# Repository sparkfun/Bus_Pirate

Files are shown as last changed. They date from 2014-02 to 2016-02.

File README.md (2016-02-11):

Bus Pirate
==========

Bus Pirate (https://cdn.sparkfun.com/assets/learn_tutorials/4/0/4/Bus_Pirate.jpg)

*Bus Pirate [(TOL-12942)](https://www.sparkfun.com/products/12942)*

This is a troubleshooting tool that communicates between a PC and any embedded device over most standard serial protocols, which
include I<sup>2</sup>C, SPI, and asynchronous serial.

Repository Contents
-------------------

* **/Hardware** &mdash; All Eagle design files (.brd, .sch)
* **/Production** &mdash; Production panel file (.brd)
* **/Software** &mdash; Minimal Python example demonstrating binary mode

Documentation
--------------
* **[Hookup Guide](https://learn.sparkfun.com/tutorials/bus-pirate-v36a-hookup-guide)** &mdash; Basic hookup guide for the Bus Pirate.
* **[SparkFun Fritzing repo](https://github.com/sparkfun/Fritzing_Parts)** &mdash; Fritzing diagrams for SparkFun products.

Product Versions
----------------
* [TOL-12942](https://www.sparkfun.com/products/12942) &mdash; Serial protocol troubleshooting tool

Version History
---------------
* [v3.6a](https://www.sparkfun.com/products/12942) &mdash; Updated main connector wire colors/locations and improved power regulation
* [v36](https://www.sparkfun.com/products/9544) &mdash; Original version produced by SparkFun

License Information
-------------------

This product is _**open source**_!

Please review the LICENSE.md file for license information.

If you have any questions or concerns on licensing, please contact techsupport@sparkfun.com.

Distributed as-is; no warranty is given.

- Your friends at SparkFun.

This is a collaboration with Ian Lesnet.

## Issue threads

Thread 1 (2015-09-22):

v3.6 Proto Checklist Issues

ericorosel, 2015-09-22:
(1) I think the Standoff drill hits should be part of a device and have a symbol in the SCH. We should use a standoff device with a symbol and a package from the eagle libraries. If we use a standardized device from the eagle library we can insure that the proper keepout and restrict elements are present, tested, and consistent.

(2) In the SCH the symbol for the cable connector uses a GND flag instead of a GND symbol on the GND net.

(3) USB connector currently has the wrong prefix in the Name field

(4) Level shifting IC currently has the wrong prefix in the Name field

(5) USB needs Tnames and Tvalues elements in the SCH

(6) 3.3V and 5V output traces from the vregs both have 20mil vias that are not masked on top or bottom. For testing purposes I only need the bottoms of the vias unmasked. Unless there is reasoning, I think the tops of these vias should be masked.

(7) VCC trace has two 20mil vias  that are not masked on top and bottom. I only need one of these vias unmasked on the bottom for testing (either one works for me), and unless there is reasoning, I think the tops of these vias should be masked.

(8) There are two GND vias that are unmasked on the top and the bottom. One is above the 1x5 header and one is to the left of the 2X5 connector. I think that both of these need mask on top and bottom unless there is a reason.

(9) R1, R5, R8 and all of the resistor arrays need some sort of silk in the package.

(10) Logic shifting IC needs a tPlace polarity marker that is outside of the package.

BrentWilkins, 2015-09-23:
(1) This isn't our design.  It's using the 'DP6037' standard PCB footprint.
(2) Changed to our standard.
(3) Using an industry standard name (https://en.wikipedia.org/wiki/Reference_designator) to not confuse it with a jumper (JP).  Not alright?
(4) Changed for similar reason as (3).
(5) FIxed on our library
(6) That is caused by our standard DRC by the limit option under masks.  Should I change the DRC? I unmasked one of the vias on the 5V bus for you on the bottom only.  Interesting that none of us have used larger vias for more current capacity and uncovered this before(?)
(7) See response to (6)
(8) See response to (6)
(9) Added a rectangle that doesn't overlap tStop
(10) Moved out

ericorosel, 2015-10-05:
Sorry it's been so long on this, I unsubscribe to repos so I never receive any notifications from activity on them.

(1) if the design is using a standard footprint 'DP6037' I think there needs to be a symbol for the footprint within schematic, or the standoffs need a symbol.

(2) Thanks

(3) We've (QC) been using the engineering 'eagle rules' wiki for reference on prefixes. I agree with you that JP is not the appropriate prefix per the industry standard, but according the the Engineering Wiki, it is what we use for connectors. Maybe there is en explanation from someone in engineering as to why we have a different set of prefixes than the industry standard.

(4) Thanks

(5) Thanks

(6) I see what you are talking about. I'm not entirely sure why we have the limit set to 20 mil. My only thought being that perhaps the drill is large enough that the mask would cover the metal on the top and the bottom of the via, but there would still be a hole that is not really masked closed? Or maybe it's something specific to GP? Having the vias unmasked on the top isn't the end of the world, but I would generally like to stay away from exposing metal unnecessarily, especially when it's metal on PWR or GND lines. Honestly, I think we could order protos with the tStop present, but I would like to get an explanation from engineering about why the 'limit' in the DRC is set to 20 mil.

(7) and (8) same as '(6)'

(9) thanks

(10) thanks

BrentWilkins, 2015-10-08:
(1) I copied the one from their library and increased the width of the dimension to meet our 8mil spec.
(3) The DFM group is aware of this.  We can change it later if we decide not to improve our rules. It shouldn't delay this project.
(6) I increased it to 30mil for this board and manually added bStop for VCC, 5V, SW3V3, & SW5V0.

ericorosel, 2015-10-08:
Pete informed me that the DFM group is looking into the prefixes that we use. Thanks for making that happen.

thanks for the fixes

Closed 2015-10-08.

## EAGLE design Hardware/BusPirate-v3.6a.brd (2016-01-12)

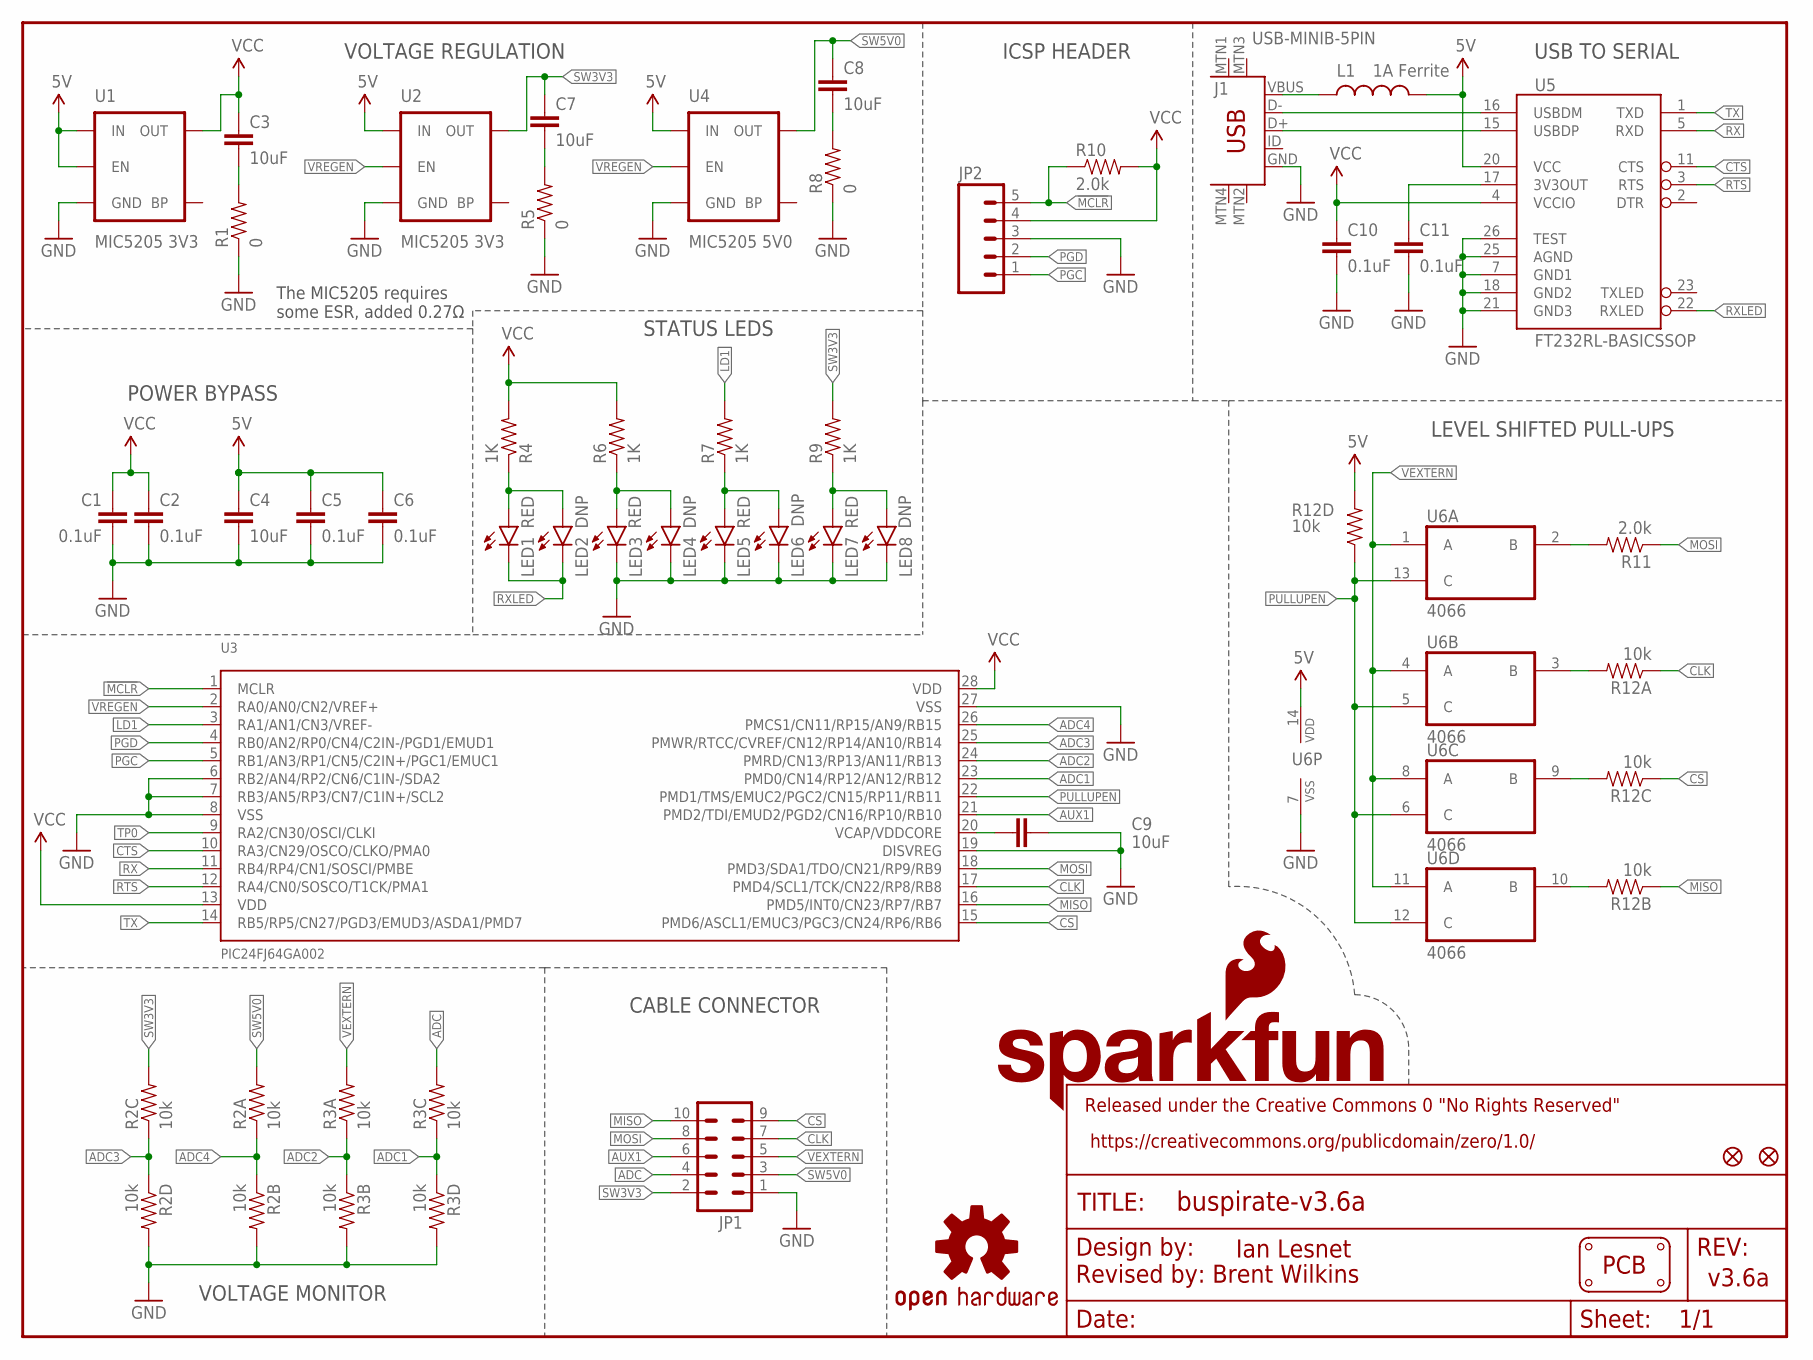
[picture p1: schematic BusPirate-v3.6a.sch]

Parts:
C1, C2, C5, C6, C10, C11: 0.1uF; 0603-CAP
C3, C4, C7, C8, C9: 10uF; 0805-CAP
FID1, FID2: FIDUCIAL1X2; FIDUCIAL-1X2
J1: USB-MINIB-5PIN; USB-MINIB
JP1: M05X2SHD_SMD; 2X5-SHROUDED_SMD
JP2: M05PTH; 1X05
L1: 1A Ferrite; 0603
LED1, LED3, LED5, LED7: RED; LED-0603
LED2, LED4, LED6, LED8: DNP; LED-0603
LOGO1: OSHW-LOGOL; OSHW-LOGO-L
LOGO2: SFE_LOGO_NAME_FLAME.1_INCH; SFE_LOGO_NAME_FLAME_.1
PCB1: PCB_DP_RECTANGLE-37X60; DP6037_V1
R1, R5, R8: 0; 0603
R2, R3, R12: 10k; 4XARRAY
R4, R6, R7, R9: 1K; 0603-RES
R10, R11: 2.0k; 0603-RES
U1, U2: MIC5205 3V3; SOT23-5
U3: PIC24FJ64GA002; SSOP28
U4: MIC5205 5V0; SOT23-5
U5: FT232RL-BASICSSOP; SSOP28DB
U6: 4066; TSSOP14

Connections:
5V: C4.1, C5.1, C6.1, L1.2, R12.5 (2), U1.1 (IN), U1.3 (EN), U2.1 (IN), U4.1 (IN), U5.20 (VCC), U6.14 (VDD)
!MCLR: JP2.5, R10.1, U3.1 (MCLR)
$N26: J1.VBUS, L1.1
ADC: JP1.4, R3.6 (2)
ADC1: R3.3 (1), R3.4 (1), U3.23 (PMD0/CN14/RP12/AN12/RB12)
ADC2: R3.1, R3.2 (1), U3.24 (PMRD/CN13/RP13/AN11/RB13)
ADC3: R2.3 (1), R2.4 (1), U3.25 (PMWR/RTCC/CVREF/CN12/RP14/AN10/RB14)
ADC4: R2.1, R2.2 (1), U3.26 (PMCS1/CN11/RP15/AN9/RB15)
AUX1: JP1.6, U3.21 (PMD2/TDI/EMUD2/PGD2/CN16/RP10/RB10)
CLK: JP1.7, R12.1, U3.17 (PMD4/SCL1/TCK/CN22/RP8/RB8)
CS: JP1.9, R12.3 (1), U3.15 (PMD6/ASCL1/EMUC3/PGC3/CN24/RP6/RB6)
CTS: U3.10 (RA3/CN29/OSCO/CLKO/PMA0), U5.11 (CTS)
D+: J1.D+, U5.15 (USBDP)
D-: J1.D-, U5.16 (USBDM)
GND: C1.2, C2.2, C4.2, C5.2, C6.2, C9.2, C10.2, C11.2, J1.GND, JP1.1, JP2.3, LED3.C, LED4.C, LED5.C, LED6.C, LED7.C, LED8.C, R1.1, R2.5 (2), R2.7 (2), R3.5 (2), R3.7 (2), R5.1, R8.1, U1.2 (GND), U2.2 (GND), U3.6 (RB2/AN4/RP2/CN6/C1IN-/SDA2), U3.7 (RB3/AN5/RP3/CN7/C1IN+/SCL2), U3.8 (VSS), U3.19 (DISVREG), U3.27 (VSS), U4.2 (GND), U5.7 (GND1), U5.18 (GND2), U5.21 (GND3), U5.25 (AGND), U5.26 (TEST), U6.7 (VSS)
LD1: R7.2, U3.3 (RA1/AN1/CN3/VREF-)
MISO: JP1.10, R12.2 (1), U3.16 (PMD5/INT0/CN23/RP7/RB7)
MOSI: JP1.8, R11.1, U3.18 (PMD3/SDA1/TDO/CN21/RP9/RB9)
unnamed: R11.2, U6.2 (B)
unnamed: R12.6 (2), U6.9 (B)
unnamed: C9.1, U3.20 (VCAP/VDDCORE)
unnamed: R12.7 (2), U6.10 (B)
unnamed: R12.8 (2), U6.3 (B)
unnamed: LED5.A, LED6.A, R7.1
unnamed: LED3.A, LED4.A, R6.1
unnamed: C3.2, R1.2
unnamed: C11.1, U5.17 (3V3OUT)
unnamed: C7.2, R5.2
unnamed: C8.2, R8.2
unnamed: LED1.A, LED2.A, R4.1
unnamed: LED7.A, LED8.A, R9.1
PGC: JP2.1, U3.5 (RB1/AN3/RP1/CN5/C2IN+/PGC1/EMUC1)
PGD: JP2.2, U3.4 (RB0/AN2/RP0/CN4/C2IN-/PGD1/EMUD1)
PULLUPEN: R12.4 (1), U3.22 (PMD1/TMS/EMUC2/PGC2/CN15/RP11/RB11), U6.5 (C), U6.6 (C), U6.12 (C), U6.13 (C)
RTS: U3.12 (RA4/CN0/SOSCO/T1CK/PMA1), U5.3 (RTS)
RX: U3.11 (RB4/RP4/CN1/SOSCI/PMBE), U5.5 (RXD)
RXLED: LED1.C, LED2.C, U5.22 (RXLED)
SW3V3: C7.1, JP1.2, R2.6 (2), R9.2, U2.5 (OUT)
SW5V0: C8.1, JP1.3, R2.8 (2), U4.5 (OUT)
TP0: U3.9 (RA2/CN30/OSCI/CLKI)
TX: U3.14 (RB5/RP5/CN27/PGD3/EMUD3/ASDA1/PMD7), U5.1 (TXD)
VCC: C1.1, C2.1, C3.1, C10.1, JP2.4, R4.2, R6.2, R10.2, U1.5 (OUT), U3.13 (VDD), U3.28 (VDD), U5.4 (VCCIO)
VEXTERN: JP1.5, R3.8 (2), U6.1 (A), U6.4 (A), U6.8 (A), U6.11 (A)
VREGEN: U2.3 (EN), U3.2 (RA0/AN0/CN2/VREF+), U4.3 (EN)

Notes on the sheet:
Revised by: Brent Wilkins
Ian Lesnet
v3.6a
VOLTAGE REGULATION
VOLTAGE MONITOR
USB TO SERIAL
STATUS LEDS
POWER BYPASS
ICSP HEADER
LEVEL SHIFTED PULL-UPS
CABLE CONNECTOR
The MIC5205 requires some ESR, added 0.27Ω
Date:
Sheet:
REV:
TITLE:
Released under the Creative Commons 0 "No Rights Reserved"
https://creativecommons.org/publicdomain/zero/1.0/
Design by:

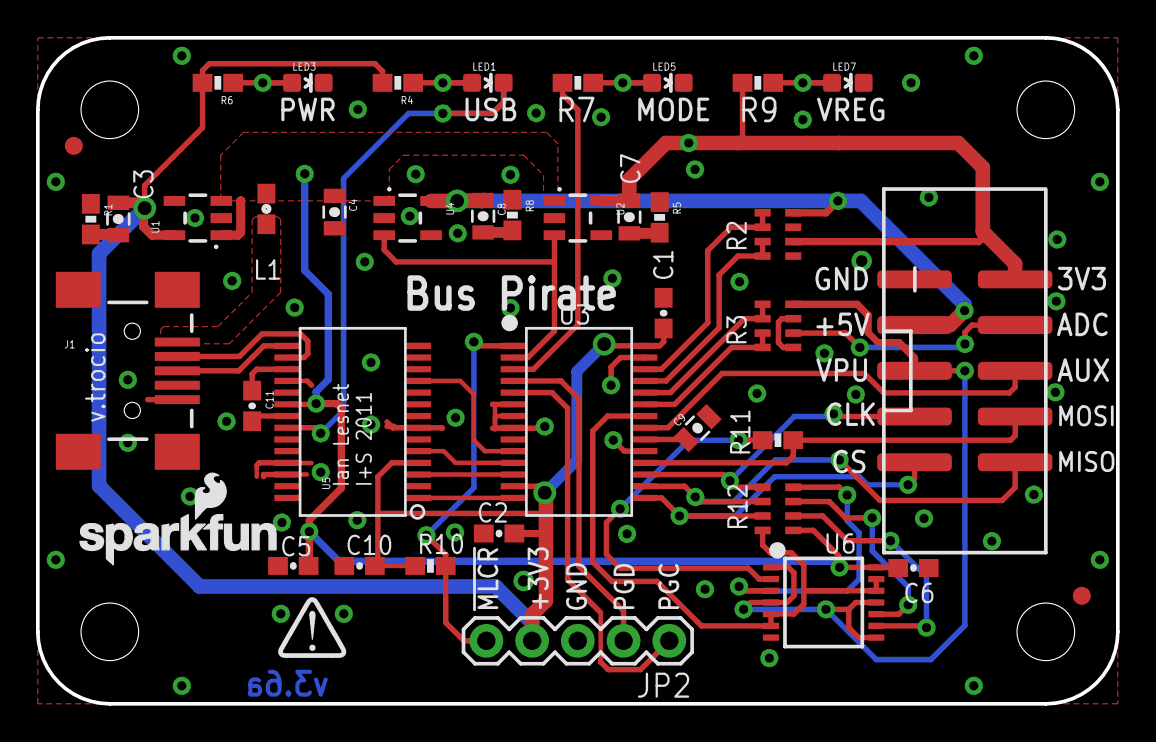
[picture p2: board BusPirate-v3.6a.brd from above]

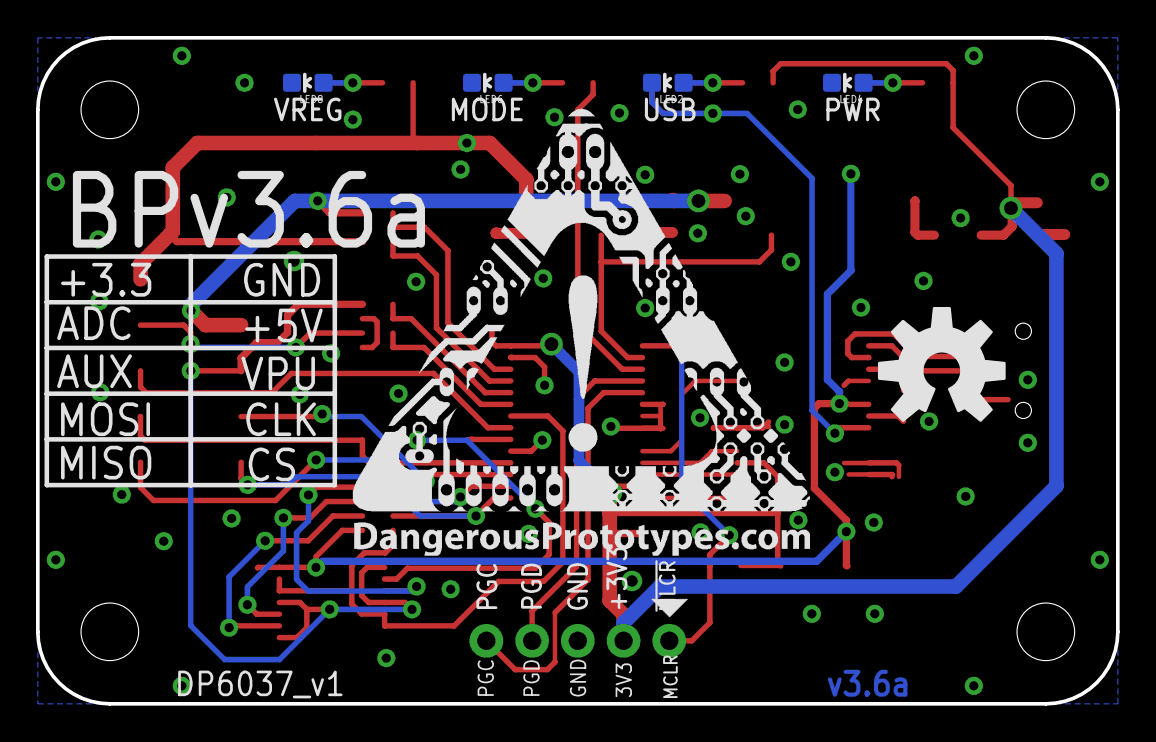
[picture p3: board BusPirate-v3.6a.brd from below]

Board: 2 copper layers, 60.0 x 37.0 mm, 48 parts (6 on the bottom side), 43 nets.

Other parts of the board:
U$1: DP-LOGO
U$3: DP_LOGO_ART_1X1

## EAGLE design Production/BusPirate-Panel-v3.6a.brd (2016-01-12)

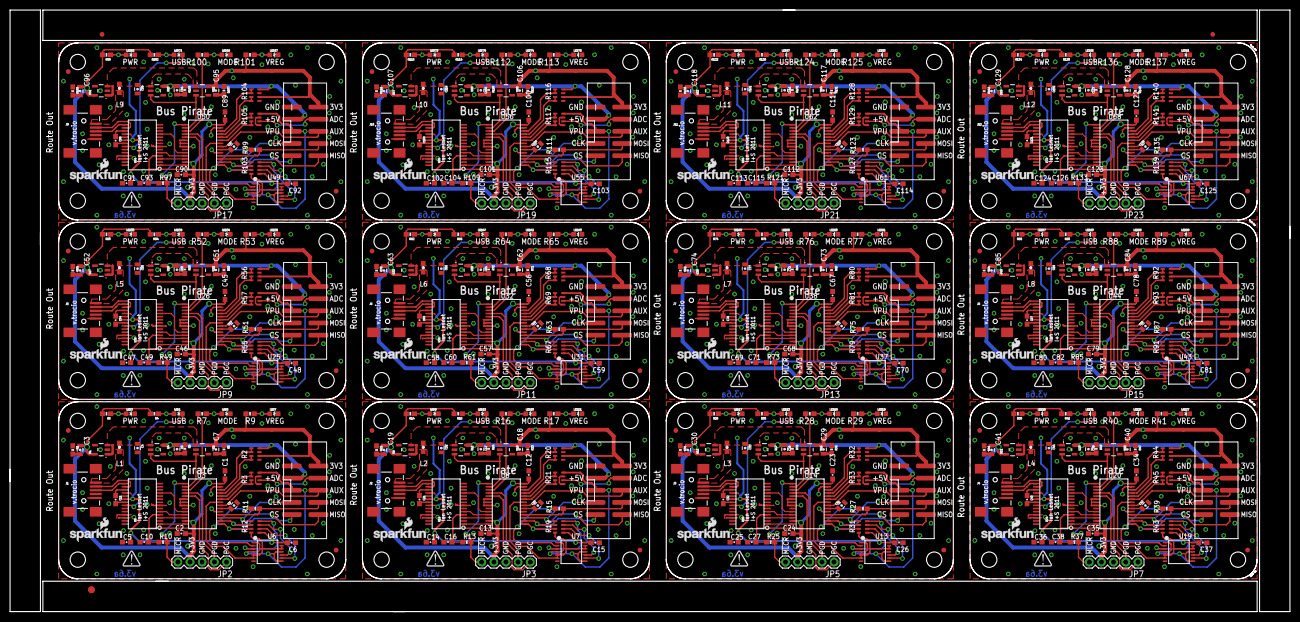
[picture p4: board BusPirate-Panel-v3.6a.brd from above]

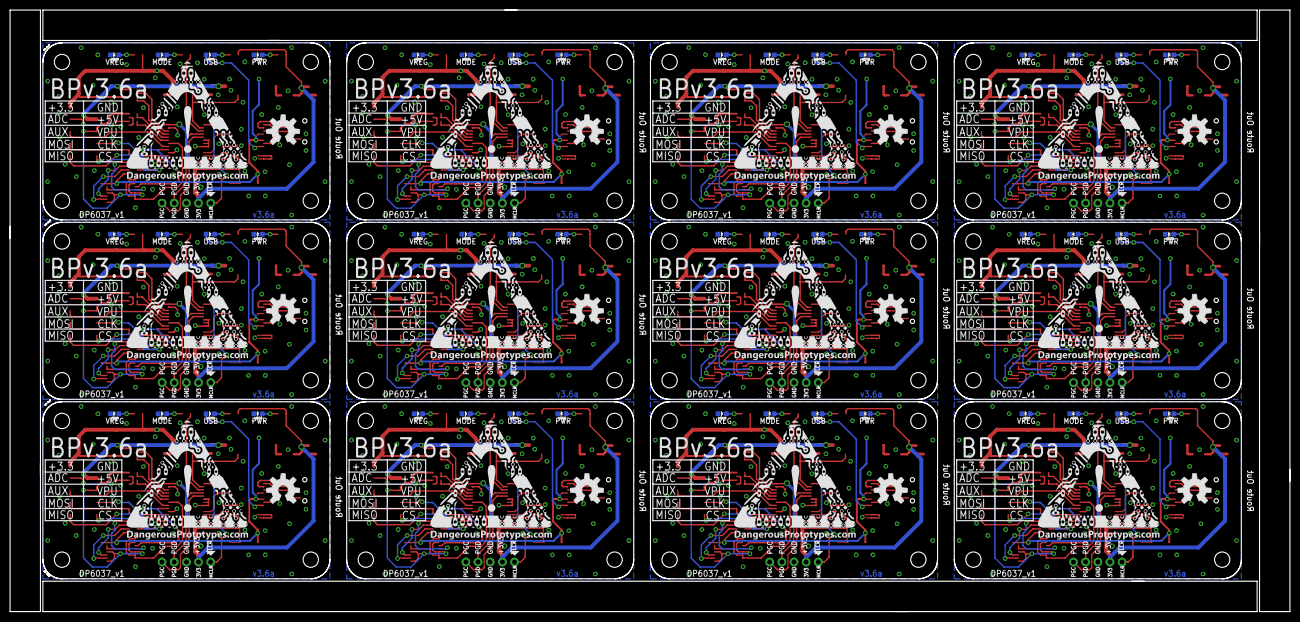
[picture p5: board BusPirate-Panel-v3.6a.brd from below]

Board: 2 copper layers, 267.5 x 125.7 mm, 579 parts (72 on the bottom side), 516 nets.

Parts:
C1, C2, C5, C6, C10, C11, C12, C13, C14, C15, C16, C21, C23, C24, C25, C26, C27, C32, C34, C35, C36, C37, C38, C43, C45, C46, C47, C48, C49, C54, C56, C57, C58, C59, C60, C65, C67, C68, C69, C70, C71, C76, C78, C79, C80, C81, C82, C87, C89, C90, C91, C92, C93, C98, C100, C101, C102, C103, C104, C109, C111, C112, C113, C114, C115, C120, C122, C123, C124, C125, C126, C131: 0.1uF; 0603-CAP
C3, C4, C7, C8, C9, C17, C18, C19, C20, C22, C28, C29, C30, C31, C33, C39, C40, C41, C42, C44, C50, C51, C52, C53, C55, C61, C62, C63, C64, C66, C72, C73, C74, C75, C77, C83, C84, C85, C86, C88, C94, C95, C96, C97, C99, C105, C106, C107, C108, C110, C116, C117, C118, C119, C121, C127, C128, C129, C130, C132: 10uF; 0805-CAP
E$1: FIDUCIAL-1.5X3
E$7, E$8: FIDUCIAL-1X2
FID1, FID2, FID3, FID4, FID5, FID6, FID7, FID8, FID9, FID10, FID11, FID12, FID13, FID14, FID15, FID16, FID17, FID18, FID19, FID20, FID21, FID22, FID23, FID24: FIDUCIAL1X2; FIDUCIAL-1X2
J1, J2, J3, J4, J5, J6, J7, J8, J9, J10, J11, J12: USB-MINIB-5PIN; USB-MINIB
JP1, JP4, JP6, JP8, JP10, JP12, JP14, JP16, JP18, JP20, JP22, JP24: 2X5-SHROUDED_SMD
JP2, JP3, JP5, JP7, JP9, JP11, JP13, JP15, JP17, JP19, JP21, JP23: 1X05
L1, L2, L3, L4, L5, L6, L7, L8, L9, L10, L11, L12: 1A Ferrite; 0603
LED1, LED3, LED5, LED7, LED9, LED10, LED11, LED15, LED17, LED18, LED19, LED23, LED25, LED26, LED27, LED31, LED33, LED34, LED35, LED39, LED41, LED42, LED43, LED47, LED49, LED50, LED51, LED55, LED57, LED58, LED59, LED63, LED65, LED66, LED67, LED71, LED73, LED74, LED75, LED79, LED81, LED82, LED83, LED87, LED89, LED90, LED91, LED95: RED; LED-0603
LED2, LED4, LED6, LED8, LED12, LED13, LED14, LED16, LED20, LED21, LED22, LED24, LED28, LED29, LED30, LED32, LED36, LED37, LED38, LED40, LED44, LED45, LED46, LED48, LED52, LED53, LED54, LED56, LED60, LED61, LED62, LED64, LED68, LED69, LED70, LED72, LED76, LED77, LED78, LED80, LED84, LED85, LED86, LED88, LED92, LED93, LED94, LED96: DNP; LED-0603
LOGO1, LOGO4, LOGO6, LOGO8, LOGO10, LOGO12, LOGO14, LOGO16, LOGO18, LOGO20, LOGO22, LOGO24: OSHW-LOGOL; OSHW-LOGO-L
LOGO2, LOGO3, LOGO5, LOGO7, LOGO9, LOGO11, LOGO13, LOGO15, LOGO17, LOGO19, LOGO21, LOGO23: SFE_LOGO_NAME_FLAME.1_INCH; SFE_LOGO_NAME_FLAME_.1
PCB1, PCB2, PCB3, PCB4, PCB5, PCB6, PCB7, PCB8, PCB9, PCB10, PCB11, PCB12: PCB_DP_RECTANGLE-37X60; DP6037_V1
R1, R5, R8, R22, R23, R24, R34, R35, R36, R46, R47, R48, R58, R59, R60, R70, R71, R72, R82, R83, R84, R94, R95, R96, R106, R107, R108, R118, R119, R120, R130, R131, R132, R142, R143, R144: 0; 0603
R2, R3, R12, R19, R20, R21, R31, R32, R33, R43, R44, R45, R55, R56, R57, R67, R68, R69, R79, R80, R81, R91, R92, R93, R103, R104, R105, R115, R116, R117, R127, R128, R129, R139, R140, R141: 10k; 4XARRAY
R4, R6, R7, R9, R14, R16, R17, R18, R26, R28, R29, R30, R38, R40, R41, R42, R50, R52, R53, R54, R62, R64, R65, R66, R74, R76, R77, R78, R86, R88, R89, R90, R98, R100, R101, R102, R110, R112, R113, R114, R122, R124, R125, R126, R134, R136, R137, R138: 1K; 0603-RES
R10, R11, R13, R15, R25, R27, R37, R39, R49, R51, R61, R63, R73, R75, R85, R87, R97, R99, R109, R111, R121, R123, R133, R135: 2.0k; 0603-RES
U1, U2, U9, U10, U15, U16, U21, U22, U27, U28, U33, U34, U39, U40, U45, U46, U51, U52, U57, U58, U63, U64, U69, U70: MIC5205 3V3; SOT23-5
U3, U8, U14, U20, U26, U32, U38, U44, U50, U56, U62, U68: PIC24FJ64GA002; SSOP28
U4, U11, U17, U23, U29, U35, U41, U47, U53, U59, U65, U71: MIC5205 5V0; SOT23-5
U5, U12, U18, U24, U30, U36, U42, U48, U54, U60, U66, U72: FT232RL-BASICSSOP; SSOP28DB
U6, U7, U13, U19, U25, U31, U37, U43, U49, U55, U61, U67: 4066; TSSOP14
U$1, U$2, U$5, U$7, U$9, U$11, U$13, U$15, U$17, U$19, U$21, U$23: DP-LOGO
U$3, U$4, U$6, U$8, U$10, U$12, U$14, U$16, U$18, U$20, U$22, U$24: DP_LOGO_ART_1X1

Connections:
5V: C4.1, C5.1, C6.1, L1.2, R12.5, U1.1, U1.3, U2.1, U4.1, U5.20, U6.14
5V1: C14.1, C15.1, C22.1, L2.2, R19.5, U7.14, U9.1, U9.3, U10.1, U11.1, U12.20
5V2: C25.1, C26.1, C33.1, L3.2, R31.5, U13.14, U15.1, U15.3, U16.1, U17.1, U18.20
5V3: C36.1, C37.1, C44.1, L4.2, R43.5, U19.14, U21.1, U21.3, U22.1, U23.1, U24.20
5V4: C47.1, C48.1, C55.1, L5.2, R55.5, U25.14, U27.1, U27.3, U28.1, U29.1, U30.20
5V5: C58.1, C59.1, C66.1, L6.2, R67.5, U31.14, U33.1, U33.3, U34.1, U35.1, U36.20
5V6: C69.1, C70.1, C77.1, L7.2, R79.5, U37.14, U39.1, U39.3, U40.1, U41.1, U42.20
5V7: C80.1, C81.1, C88.1, L8.2, R91.5, U43.14, U45.1, U45.3, U46.1, U47.1, U48.20
5V8: C91.1, C92.1, C99.1, L9.2, R103.5, U49.14, U51.1, U51.3, U52.1, U53.1, U54.20
5V9: C102.1, C103.1, C110.1, L10.2, R115.5, U55.14, U57.1, U57.3, U58.1, U59.1, U60.20
5V10: C113.1, C114.1, C121.1, L11.2, R127.5, U61.14, U63.1, U63.3, U64.1, U65.1, U66.20
5V11: C124.1, C125.1, C132.1, L12.2, R139.5, U67.14, U69.1, U69.3, U70.1, U71.1, U72.20
!MCLR: JP2.5, R10.1, U3.1
!MCLR1: JP3.5, R13.1, U8.1
!MCLR2: JP5.5, R25.1, U14.1
!MCLR3: JP7.5, R37.1, U20.1
!MCLR4: JP9.5, R49.1, U26.1
!MCLR5: JP11.5, R61.1, U32.1
!MCLR6: JP13.5, R73.1, U38.1
!MCLR7: JP15.5, R85.1, U44.1
!MCLR8: JP17.5, R97.1, U50.1
!MCLR9: JP19.5, R109.1, U56.1
!MCLR10: JP21.5, R121.1, U62.1
!MCLR11: JP23.5, R133.1, U68.1
$N1: J2.VBUS, L2.1
$N2: J3.VBUS, L3.1
$N3: J4.VBUS, L4.1
$N4: J5.VBUS, L5.1
$N5: J6.VBUS, L6.1
$N6: J7.VBUS, L7.1
$N7: J8.VBUS, L8.1
$N8: J9.VBUS, L9.1
$N9: J10.VBUS, L10.1
$N10: J11.VBUS, L11.1
$N11: J12.VBUS, L12.1
$N26: J1.VBUS, L1.1
ADC: JP1.4, R3.6
ADC1: R3.3, R3.4, U3.23
ADC2: R3.1, R3.2, U3.24
ADC3: R2.3, R2.4, U3.25
ADC4: R2.1, R2.2, U3.26
ADC5: R21.3, R21.4, U8.23
ADC6: JP4.4, R21.6
ADC7: R21.1, R21.2, U8.24
ADC8: R20.3, R20.4, U8.25
ADC9: R20.1, R20.2, U8.26
ADC10: R33.3, R33.4, U14.23
ADC11: JP6.4, R33.6
ADC12: R33.1, R33.2, U14.24
ADC13: R32.3, R32.4, U14.25
ADC14: R32.1, R32.2, U14.26
ADC15: R45.3, R45.4, U20.23
ADC16: JP8.4, R45.6
ADC17: R45.1, R45.2, U20.24
ADC18: R44.3, R44.4, U20.25
ADC19: R44.1, R44.2, U20.26
ADC20: R57.3, R57.4, U26.23
ADC21: JP10.4, R57.6
ADC22: R57.1, R57.2, U26.24
ADC23: R56.3, R56.4, U26.25
ADC24: R56.1, R56.2, U26.26
ADC25: R69.3, R69.4, U32.23
ADC26: JP12.4, R69.6
ADC27: R69.1, R69.2, U32.24
ADC28: R68.3, R68.4, U32.25
ADC29: R68.1, R68.2, U32.26
ADC30: R81.3, R81.4, U38.23
ADC31: JP14.4, R81.6
ADC32: R81.1, R81.2, U38.24
ADC33: R80.3, R80.4, U38.25
ADC34: R80.1, R80.2, U38.26
ADC35: R93.3, R93.4, U44.23
ADC36: JP16.4, R93.6
ADC37: R93.1, R93.2, U44.24
ADC38: R92.3, R92.4, U44.25
ADC39: R92.1, R92.2, U44.26
ADC40: R105.3, R105.4, U50.23
ADC41: JP18.4, R105.6
ADC42: R105.1, R105.2, U50.24
ADC43: R104.3, R104.4, U50.25
ADC44: R104.1, R104.2, U50.26
ADC45: R117.3, R117.4, U56.23
ADC46: JP20.4, R117.6
ADC47: R117.1, R117.2, U56.24
ADC48: R116.3, R116.4, U56.25
ADC49: R116.1, R116.2, U56.26
ADC50: R129.3, R129.4, U62.23
ADC51: JP22.4, R129.6
ADC52: R129.1, R129.2, U62.24
ADC53: R128.3, R128.4, U62.25
ADC54: R128.1, R128.2, U62.26
ADC55: R141.3, R141.4, U68.23
ADC56: JP24.4, R141.6
ADC57: R141.1, R141.2, U68.24
ADC58: R140.3, R140.4, U68.25
ADC59: R140.1, R140.2, U68.26
AUX1: JP1.6, U3.21
AUX2: JP4.6, U8.21
AUX3: JP6.6, U14.21
AUX4: JP8.6, U20.21
AUX5: JP10.6, U26.21
AUX6: JP12.6, U32.21
AUX7: JP14.6, U38.21
AUX8: JP16.6, U44.21
AUX9: JP18.6, U50.21
AUX10: JP20.6, U56.21
AUX11: JP22.6, U62.21
AUX12: JP24.6, U68.21
CLK: JP1.7, R12.1, U3.17
CLK1: JP4.7, R19.1, U8.17
CLK2: JP6.7, R31.1, U14.17
CLK3: JP8.7, R43.1, U20.17
CLK4: JP10.7, R55.1, U26.17
CLK5: JP12.7, R67.1, U32.17
CLK6: JP14.7, R79.1, U38.17
CLK7: JP16.7, R91.1, U44.17
CLK8: JP18.7, R103.1, U50.17
CLK9: JP20.7, R115.1, U56.17
CLK10: JP22.7, R127.1, U62.17
CLK11: JP24.7, R139.1, U68.17
CS: JP1.9, R12.3, U3.15
CS1: JP4.9, R19.3, U8.15
CS2: JP6.9, R31.3, U14.15
CS3: JP8.9, R43.3, U20.15
CS4: JP10.9, R55.3, U26.15
CS5: JP12.9, R67.3, U32.15
CS6: JP14.9, R79.3, U38.15
CS7: JP16.9, R91.3, U44.15
CS8: JP18.9, R103.3, U50.15
CS9: JP20.9, R115.3, U56.15
CS10: JP22.9, R127.3, U62.15
CS11: JP24.9, R139.3, U68.15
CTS: U3.10, U5.11
CTS1: U8.10, U12.11
CTS2: U14.10, U18.11
CTS3: U20.10, U24.11
CTS4: U26.10, U30.11
CTS5: U32.10, U36.11
CTS6: U38.10, U42.11
CTS7: U44.10, U48.11
CTS8: U50.10, U54.11
CTS9: U56.10, U60.11
CTS10: U62.10, U66.11
CTS11: U68.10, U72.11
D+: J1.D+, U5.15
D+1: J2.D+, U12.15
D+2: J3.D+, U18.15
D+3: J4.D+, U24.15
D+4: J5.D+, U30.15
D+5: J6.D+, U36.15
D+6: J7.D+, U42.15
D+7: J8.D+, U48.15
D+8: J9.D+, U54.15
D+9: J10.D+, U60.15
D+10: J11.D+, U66.15
D+11: J12.D+, U72.15
D-: J1.D-, U5.16
D-1: J2.D-, U12.16
D-2: J3.D-, U18.16
D-3: J4.D-, U24.16
D-4: J5.D-, U30.16
D-5: J6.D-, U36.16
D-6: J7.D-, U42.16
D-7: J8.D-, U48.16
D-8: J9.D-, U54.16
D-9: J10.D-, U60.16
D-10: J11.D-, U66.16
D-11: J12.D-, U72.16
GND: C1.2, C2.2, C4.2, C5.2, C6.2, C9.2, C10.2, C11.2, J1.GND, JP1.1, JP2.3, LED3.C, LED4.C, LED5.C, LED6.C, LED7.C, LED8.C, R1.1, R2.5, R2.7, R3.5, R3.7, R5.1, R8.1, U1.2, U2.2, U3.6, U3.7, U3.8, U3.19, U3.27, U4.2, U5.7, U5.18, U5.21, U5.25, U5.26, U6.7
GND1: C12.2, C13.2, C14.2, C15.2, C16.2, C20.2, C21.2, C22.2, J2.GND, JP3.3, JP4.1, LED9.C, LED10.C, LED11.C, LED12.C, LED13.C, LED14.C, R20.5, R20.7, R21.5, R21.7, R22.1, R23.1, R24.1, U7.7, U8.6, U8.7, U8.8, U8.19, U8.27, U9.2, U10.2, U11.2, U12.7, U12.18, U12.21, U12.25, U12.26
GND2: C23.2, C24.2, C25.2, C26.2, C27.2, C31.2, C32.2, C33.2, J3.GND, JP5.3, JP6.1, LED17.C, LED18.C, LED19.C, LED20.C, LED21.C, LED22.C, R32.5, R32.7, R33.5, R33.7, R34.1, R35.1, R36.1, U13.7, U14.6, U14.7, U14.8, U14.19, U14.27, U15.2, U16.2, U17.2, U18.7, U18.18, U18.21, U18.25, U18.26
GND3: C34.2, C35.2, C36.2, C37.2, C38.2, C42.2, C43.2, C44.2, J4.GND, JP7.3, JP8.1, LED25.C, LED26.C, LED27.C, LED28.C, LED29.C, LED30.C, R44.5, R44.7, R45.5, R45.7, R46.1, R47.1, R48.1, U19.7, U20.6, U20.7, U20.8, U20.19, U20.27, U21.2, U22.2, U23.2, U24.7, U24.18, U24.21, U24.25, U24.26
GND4: C45.2, C46.2, C47.2, C48.2, C49.2, C53.2, C54.2, C55.2, J5.GND, JP9.3, JP10.1, LED33.C, LED34.C, LED35.C, LED36.C, LED37.C, LED38.C, R56.5, R56.7, R57.5, R57.7, R58.1, R59.1, R60.1, U25.7, U26.6, U26.7, U26.8, U26.19, U26.27, U27.2, U28.2, U29.2, U30.7, U30.18, U30.21, U30.25, U30.26
GND5: C56.2, C57.2, C58.2, C59.2, C60.2, C64.2, C65.2, C66.2, J6.GND, JP11.3, JP12.1, LED41.C, LED42.C, LED43.C, LED44.C, LED45.C, LED46.C, R68.5, R68.7, R69.5, R69.7, R70.1, R71.1, R72.1, U31.7, U32.6, U32.7, U32.8, U32.19, U32.27, U33.2, U34.2, U35.2, U36.7, U36.18, U36.21, U36.25, U36.26
GND6: C67.2, C68.2, C69.2, C70.2, C71.2, C75.2, C76.2, C77.2, J7.GND, JP13.3, JP14.1, LED49.C, LED50.C, LED51.C, LED52.C, LED53.C, LED54.C, R80.5, R80.7, R81.5, R81.7, R82.1, R83.1, R84.1, U37.7, U38.6, U38.7, U38.8, U38.19, U38.27, U39.2, U40.2, U41.2, U42.7, U42.18, U42.21, U42.25, U42.26
GND7: C78.2, C79.2, C80.2, C81.2, C82.2, C86.2, C87.2, C88.2, J8.GND, JP15.3, JP16.1, LED57.C, LED58.C, LED59.C, LED60.C, LED61.C, LED62.C, R92.5, R92.7, R93.5, R93.7, R94.1, R95.1, R96.1, U43.7, U44.6, U44.7, U44.8, U44.19, U44.27, U45.2, U46.2, U47.2, U48.7, U48.18, U48.21, U48.25, U48.26
GND8: C89.2, C90.2, C91.2, C92.2, C93.2, C97.2, C98.2, C99.2, J9.GND, JP17.3, JP18.1, LED65.C, LED66.C, LED67.C, LED68.C, LED69.C, LED70.C, R104.5, R104.7, R105.5, R105.7, R106.1, R107.1, R108.1, U49.7, U50.6, U50.7, U50.8, U50.19, U50.27, U51.2, U52.2, U53.2, U54.7, U54.18, U54.21, U54.25, U54.26
GND9: C100.2, C101.2, C102.2, C103.2, C104.2, C108.2, C109.2, C110.2, J10.GND, JP19.3, JP20.1, LED73.C, LED74.C, LED75.C, LED76.C, LED77.C, LED78.C, R116.5, R116.7, R117.5, R117.7, R118.1, R119.1, R120.1, U55.7, U56.6, U56.7, U56.8, U56.19, U56.27, U57.2, U58.2, U59.2, U60.7, U60.18, U60.21, U60.25, U60.26
GND10: C111.2, C112.2, C113.2, C114.2, C115.2, C119.2, C120.2, C121.2, J11.GND, JP21.3, JP22.1, LED81.C, LED82.C, LED83.C, LED84.C, LED85.C, LED86.C, R128.5, R128.7, R129.5, R129.7, R130.1, R131.1, R132.1, U61.7, U62.6, U62.7, U62.8, U62.19, U62.27, U63.2, U64.2, U65.2, U66.7, U66.18, U66.21, U66.25, U66.26
GND11: C122.2, C123.2, C124.2, C125.2, C126.2, C130.2, C131.2, C132.2, J12.GND, JP23.3, JP24.1, LED89.C, LED90.C, LED91.C, LED92.C, LED93.C, LED94.C, R140.5, R140.7, R141.5, R141.7, R142.1, R143.1, R144.1, U67.7, U68.6, U68.7, U68.8, U68.19, U68.27, U69.2, U70.2, U71.2, U72.7, U72.18, U72.21, U72.25, U72.26
LD1: R7.2, U3.3
LD2: R16.2, U8.3
LD3: R28.2, U14.3
LD4: R40.2, U20.3
LD5: R52.2, U26.3
LD6: R64.2, U32.3
LD7: R76.2, U38.3
LD8: R88.2, U44.3
LD9: R100.2, U50.3
LD10: R112.2, U56.3
LD11: R124.2, U62.3
LD12: R136.2, U68.3
MISO: JP1.10, R12.2, U3.16
MISO1: JP4.10, R19.2, U8.16
MISO2: JP6.10, R31.2, U14.16
MISO3: JP8.10, R43.2, U20.16
MISO4: JP10.10, R55.2, U26.16
MISO5: JP12.10, R67.2, U32.16
MISO6: JP14.10, R79.2, U38.16
MISO7: JP16.10, R91.2, U44.16
MISO8: JP18.10, R103.2, U50.16
MISO9: JP20.10, R115.2, U56.16
MISO10: JP22.10, R127.2, U62.16
MISO11: JP24.10, R139.2, U68.16
MOSI: JP1.8, R11.1, U3.18
MOSI1: JP4.8, R15.1, U8.18
MOSI2: JP6.8, R27.1, U14.18
MOSI3: JP8.8, R39.1, U20.18
MOSI4: JP10.8, R51.1, U26.18
MOSI5: JP12.8, R63.1, U32.18
MOSI6: JP14.8, R75.1, U38.18
MOSI7: JP16.8, R87.1, U44.18
MOSI8: JP18.8, R99.1, U50.18
MOSI9: JP20.8, R111.1, U56.18
MOSI10: JP22.8, R123.1, U62.18
MOSI11: JP24.8, R135.1, U68.18
unnamed: R11.2, U6.2
unnamed: R12.6, U6.9
unnamed: C9.1, U3.20
unnamed: R12.7, U6.10
unnamed: R12.8, U6.3
unnamed: LED5.A, LED6.A, R7.1
unnamed: LED3.A, LED4.A, R6.1
unnamed: C3.2, R1.2
unnamed: C11.1, U5.17
unnamed: C7.2, R5.2
unnamed: C8.2, R8.2
unnamed: LED9.A, LED14.A, R14.1
unnamed: LED1.A, LED2.A, R4.1
unnamed: C20.1, U8.20
unnamed: LED10.A, LED13.A, R16.1
unnamed: LED11.A, LED12.A, R17.1
unnamed: R15.2, U7.2
unnamed: LED7.A, LED8.A, R9.1
unnamed: LED15.A, LED16.A, R18.1
unnamed: C21.1, U12.17
unnamed: R19.8, U7.3
unnamed: R19.6, U7.9
unnamed: R19.7, U7.10
unnamed: C19.2, R22.2
unnamed: C18.2, R23.2
unnamed: C17.2, R24.2
unnamed: LED17.A, LED22.A, R26.1
unnamed: C31.1, U14.20
unnamed: LED18.A, LED21.A, R28.1
unnamed: LED19.A, LED20.A, R29.1
unnamed: R27.2, U13.2
unnamed: LED23.A, LED24.A, R30.1
unnamed: C32.1, U18.17
unnamed: R31.8, U13.3
unnamed: R31.6, U13.9
unnamed: R31.7, U13.10
unnamed: C30.2, R34.2
unnamed: C29.2, R35.2
unnamed: C28.2, R36.2
unnamed: LED25.A, LED30.A, R38.1
unnamed: C42.1, U20.20
unnamed: LED26.A, LED29.A, R40.1
unnamed: LED27.A, LED28.A, R41.1
unnamed: R39.2, U19.2
unnamed: LED31.A, LED32.A, R42.1
unnamed: C43.1, U24.17
unnamed: R43.8, U19.3
unnamed: R43.6, U19.9
unnamed: R43.7, U19.10
unnamed: C41.2, R46.2
unnamed: C40.2, R47.2
unnamed: C39.2, R48.2
unnamed: LED33.A, LED38.A, R50.1
unnamed: C53.1, U26.20
unnamed: LED34.A, LED37.A, R52.1
unnamed: LED35.A, LED36.A, R53.1
unnamed: R51.2, U25.2
unnamed: LED39.A, LED40.A, R54.1
unnamed: C54.1, U30.17
unnamed: R55.8, U25.3
unnamed: R55.6, U25.9
unnamed: R55.7, U25.10
unnamed: C52.2, R58.2
unnamed: C51.2, R59.2
unnamed: C50.2, R60.2
unnamed: LED41.A, LED46.A, R62.1
unnamed: C64.1, U32.20
unnamed: LED42.A, LED45.A, R64.1
unnamed: LED43.A, LED44.A, R65.1
unnamed: R63.2, U31.2
unnamed: LED47.A, LED48.A, R66.1
unnamed: C65.1, U36.17
unnamed: R67.8, U31.3
unnamed: R67.6, U31.9
unnamed: R67.7, U31.10
unnamed: C63.2, R70.2
unnamed: C62.2, R71.2
unnamed: C61.2, R72.2
unnamed: LED49.A, LED54.A, R74.1
unnamed: C75.1, U38.20
unnamed: LED50.A, LED53.A, R76.1
unnamed: LED51.A, LED52.A, R77.1
unnamed: R75.2, U37.2
unnamed: LED55.A, LED56.A, R78.1
unnamed: C76.1, U42.17
unnamed: R79.8, U37.3
unnamed: R79.6, U37.9
unnamed: R79.7, U37.10
unnamed: C74.2, R82.2
unnamed: C73.2, R83.2
unnamed: C72.2, R84.2
unnamed: LED57.A, LED62.A, R86.1
unnamed: C86.1, U44.20
unnamed: LED58.A, LED61.A, R88.1
unnamed: LED59.A, LED60.A, R89.1
unnamed: R87.2, U43.2
unnamed: LED63.A, LED64.A, R90.1
unnamed: C87.1, U48.17
unnamed: R91.8, U43.3
unnamed: R91.6, U43.9
unnamed: R91.7, U43.10
unnamed: C85.2, R94.2
unnamed: C84.2, R95.2
unnamed: C83.2, R96.2
unnamed: LED65.A, LED70.A, R98.1
unnamed: C97.1, U50.20
unnamed: LED66.A, LED69.A, R100.1
unnamed: LED67.A, LED68.A, R101.1
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

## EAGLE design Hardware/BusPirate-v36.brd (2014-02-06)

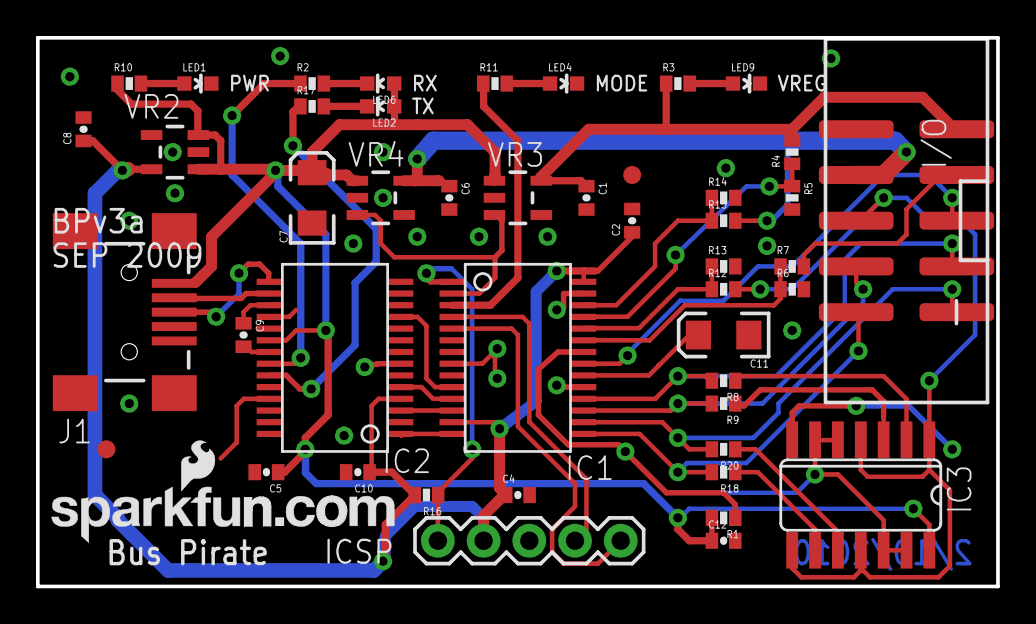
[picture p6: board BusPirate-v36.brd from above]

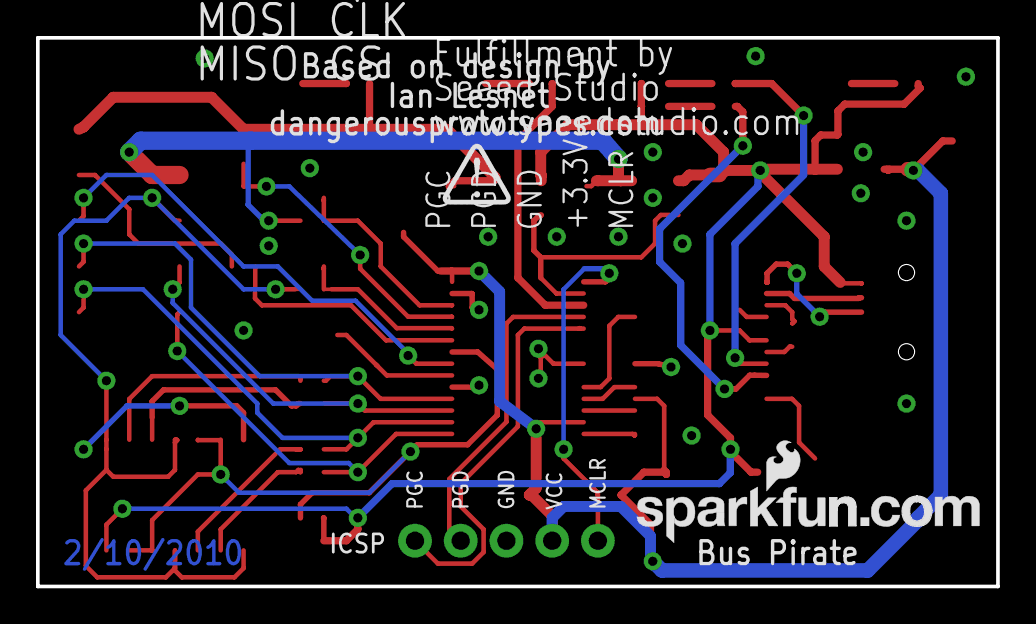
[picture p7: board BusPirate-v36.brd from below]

Board: 2 copper layers, 53.3 x 30.5 mm, 50 parts (2 on the bottom side), 41 nets.

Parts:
C1, C6, C8: 2.2uF; 0402-CAP
C2, C4, C5, C9, C10, C12: 0.1uF; 0402-CAP
C7, C11: 10uF; EIA3216
I/O: M05X2SHD_SMD; 2X5-SHROUDED_SMD
IC1: PIC24FJ64GA002-I/SSSS-ALTERNATE; SSOP28DB
IC2: FT232RLSSOP; SSOP28DB
IC3: 4066D; SO14
ICSP: M05X1PTH; 1X05
J1: USBSMD; USB-MINIB
JP1, JP2: LOGO-SFENEW; SFE-NEW-WEBLOGO
JP3, JP4: FIDUCIAL1X2; FIDUCIAL-1X2
LED1, LED4: RED; LED-0603
LED2: GREEN; LED-0603
LED6: BLUE; LED-0603
LED9: YELLOW; LED-0603
R1, R4, R5, R6, R7, R9, R12, R13, R14, R15, R18, R20: 10k; 0402-RES
R2, R10, R17: 1k1; 0402-RES
R3, R11: 390R; 0402-RES
R8, R16: 2k; 0402-RES
U$1: DP-LOGO
U$2: CREATIVE_COMMONS
VR2, VR3: 3.3V; SOT23-5
VR4: 5V; SOT23-5

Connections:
ADC: I/O.7, R7.2
ADC1: IC1.23, R6.1, R7.1
ADC2: IC1.24, R12.1, R13.1
ADC3: IC1.25, R4.1, R5.1
ADC4: IC1.26, R14.1, R15.1
AUX1: I/O.5, IC1.21
CLK: I/O.4, IC1.17, R9.2
CS: I/O.2, IC1.15, R18.2
CTS: IC1.10, IC2.11
GND: C1.2, C2.2, C4.2, C5.2, C6.2, C7.C, C8.2, C9.2, C10.2, C11.C, C12.2, I/O.10, IC1.8, IC1.19, IC1.27, IC2.7, IC2.18, IC2.21, IC2.25, IC2.26, IC3.7, ICSP.3, J1.GND, LED1.C, LED4.C, LED9.C, R5.2, R6.2, R13.2, R14.2, VR2.2, VR3.2, VR4.2
LD1: IC1.3, R11.1
MCLR: IC1.1, ICSP.1, R16.1
MISO: I/O.1, IC1.16, R20.2
MOSI: I/O.3, IC1.18, R8.2
unnamed: IC3.2, R8.1
unnamed: IC3.3, R9.1
unnamed: C11.A, IC1.20
unnamed: IC3.10, R20.1
unnamed: IC3.9, R18.1
unnamed: LED4.A, R11.2
unnamed: LED1.A, R10.2
unnamed: IC2.23, R17.1
unnamed: C9.1, IC2.17
unnamed: LED2.C, R17.2
unnamed: IC2.22, R2.1
unnamed: LED6.C, R2.2
unnamed: IC2.15, J1.D+
unnamed: IC2.16, J1.D-
unnamed: LED9.A, R3.2
PGC: IC1.5, ICSP.5
PGD: IC1.4, ICSP.4
PULLUPEN: IC1.22, IC3.5, IC3.6, IC3.12, IC3.13, R1.1
RTS: IC1.12, IC2.3
RX: IC1.11, IC2.5
SWV33: C1.1, I/O.9, R3.1, R4.2, VR3.5
SWV50: C6.1, I/O.8, R15.2, VR4.5
TX: IC1.14, IC2.1
V+: C5.1, C7.A, C12.1, IC2.20, IC3.14, J1.VBUS, LED2.A, LED6.A, R1.2, R10.1, VR2.1, VR2.3, VR3.1, VR4.1
VCC: C2.1, C4.1, C8.1, C10.1, IC1.13, IC1.28, IC2.4, ICSP.2, R16.2, VR2.5
VEXTERN: I/O.6, IC3.1, IC3.4, IC3.8, IC3.11, R12.2
VREGEN: IC1.2, VR3.3, VR4.3

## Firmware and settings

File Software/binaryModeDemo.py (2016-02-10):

#!/usr/bin/env python
# encoding: utf-8
"""
Example code to interface the Bus Pirate in binary mode
Highly based on https://github.com/themadinventor/esptool/blob/master/esptool.py
Brent Wilkins 2016

This code requires pyserial:
    $ sudo pip install pyserial
or:
    $ sudo easy_install -U pyserial
"""
import sys
import serial
import argparse

commands = {
        'BBIO1': '\x00',    # Enter reset binary mode
        'SPI1':  '\x01',    # Enter binary SPI mode
        'I2C1':  '\x02',    # Enter binary I2C mode
        'ART1':  '\x03',    # Enter binary UART mode
        '1W01':  '\x04',    # Enter binary 1-Wire mode
        'RAW1':  '\x05',    # Enter binary raw-wire mode
        'RESET': '\x0F',    # Reset Bus Pirate
        'STEST': '\x10',    # Bus Pirate self-tests
}

def arg_auto_int(x):
    return int(x, 0)

class FatalError(RuntimeError):
    """
    Wrapper class for runtime errors that aren't caused by internal bugs, but by
    Bus Pirate responses or input content.
    """
    def __init__(self, message):
        RuntimeError.__init__(self, message)

    @staticmethod
    def WithResult(message, result):
        """
        Return a fatal error object that includes the hex values of
        'result' as a string formatted argument.
        """
        return FatalError(message %  ', '.join(hex(ord(x)) for x in result))


def main():
    parser = argparse.ArgumentParser(description = 'Bus Pirate binary interface demo', prog = 'binaryModeDemo')

    parser.add_argument(
            '--port', '-p',
            help = 'Serial port device',
            default = '/dev/ttyUSB0')

    parser.add_argument(
            '--baud', '-b',
            help = 'Serial port baud rate',
            type = arg_auto_int,
            default = 115200)

    args = parser.parse_args()

    print '\nTrying port: ', args.port, ' at baudrate: ', args.baud

    try:
        port = serial.Serial(args.port, args.baud, timeout=0.1)
    except serial.serialutil.SerialException as e:
        print 'I/O error({0}): {1}'.format(e.errno, e.strerror)
        print 'Port cannot be opened'
    else:
        print 'Ready!'
        print 'Entering binary mode...\n'

        count = 0
        done = False
        while count < 20 and not done:
            count += 1
            port.write(commands.get('BBIO1'))
            #port.write('\x00')
            got = port.read(5)  # Read up to 5 bytes
            #print ':'.join('{:02x}'.format(ord(c)) for c in got)
            if got == 'BBIO1':
                done = True
        if not done:
            port.close()
            raise FatalError('Failed to enter binary mode')

        # Now that the Buspirate is in binary mode, choose a BP mode
        port.write(commands.get('RESET'))
        while True:
            got = port.readline()
            if not got:
                break
            print(got),

        """
        port.write(commands.get('SPI1'))
        got = port.read(4)
        if got == 'SPI1':
            print 'Entered binary SPI mode'
        else:
            raise FatalError('Buspirate failed to enter new mode')
        """

        port.close()

    #raise FatalError('Non-error')


if __name__ == '__main__':
    try:
        main()
    except FatalError as e:
        print '\nA fatal error occurred: %s' % e
        sys.exit(2)

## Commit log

2014-02-06 Initial file commit
    [BusPirate-v36.brd, BusPirate-v36.sch]
2015-09-15 First commit of v3.6a
    [BusPirate-v3.6a.brd, BusPirate-v3.6a.sch, BusPirate-v36.sch]
2015-09-17 Finished inital DFM
    [BusPirate-v3.6a.brd, BusPirate-v3.6a.sch]
2015-09-21 Changed from SFE to DP versioning, and changed bottom LEDs to DNP
    [BusPirate-v3.6a.brd, BusPirate-v3.6a.sch]
2015-09-21 Changed license from CC4 to CC0
    [BusPirate-v3.6a.brd, BusPirate-v3.6a.sch]
2015-09-23 Addressed issues
    [BusPirate-v3.6a.brd, BusPirate-v3.6a.sch]
2015-10-08 Imported DP PCB part, and changed DRC to allow mask to cover large vias.
    [BusPirate-v3.6a.brd, BusPirate-v3.6a.sch]
2015-11-09 Changed one PROD_ID and version number
    [BusPirate-v3.6a.brd, BusPirate-v3.6a.sch]
2015-11-18 created panel v3.6a
    [BusPirate-Panel-v3.6a.brd]
2016-01-12 Corrected resistor value
    [BusPirate-v3.6a.brd]
2016-02-10 Added license info, and fixed up the README
    [binaryModeDemo.py]

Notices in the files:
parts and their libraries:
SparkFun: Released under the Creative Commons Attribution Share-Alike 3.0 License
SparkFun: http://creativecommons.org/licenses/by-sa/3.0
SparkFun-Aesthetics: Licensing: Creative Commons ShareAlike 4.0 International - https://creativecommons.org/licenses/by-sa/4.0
